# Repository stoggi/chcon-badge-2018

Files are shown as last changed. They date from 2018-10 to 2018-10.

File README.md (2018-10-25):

# chcon-badge-2018
Hardware and Firmware for the ChCon 2018 badge

Made by [@jsstott](https://twitter.com/jsstott) and [@ryankurte](https://twitter.com/ryankurte)

## Assmebling your badge

See [ASSEMBLY.md](ASSEMBLY.md) for instructions, and ask in the [#badge](https://chcon-nz.slack.com/messages/CDN6BFPEV) channel in the [CHCon-NZ](https://join.slack.com/chcon-nz/shared_invite/MjA1MjM5NjY5ODQzLTE0OTg3MDAxOTEtNDUwZTMwMmEwYQ) Slack workspace for help.

## Programming your badge

You will need:

* A recent verison of the [Arduino IDE](https://www.arduino.cc/en/Main/Software) to compile and program the board
* The [Adafruit_NeoPixel](https://learn.adafruit.com/adafruit-neopixel-uberguide/arduino-library-installation) library to control the LEDs
* The [Digistump](https://digistump.com/wiki/digispark/tutorials/connecting) board library
* The EEPROM library found [here](https://github.com/digistump/DigistumpArduino/files/267174/EEPROM.zip) add under Sketch -> Include Library -> Include Zip
* A micro USB cable

To upload new firmware:

1. Open a sketch from the firmware directory.
2. From the Tools menu select Board -> Digispark (Default - 16.5Mhz)
3. From the Tools menu select Programmer -> Micronucleus.
4. Click "Upload" in the IDE. Plug in the badge, and wait 5 seconds.

> Note: Make sure your badge is powered OFF before you plug it into your computer! You can remove the battery for extra safety.

## Badge Challenge

See [CHALLENGE.md](CHALLENGE.md) to get started...

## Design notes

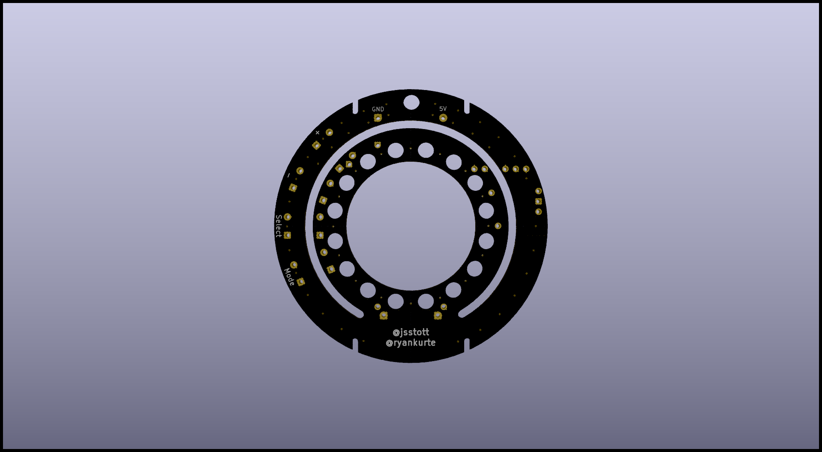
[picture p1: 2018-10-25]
images/back.png

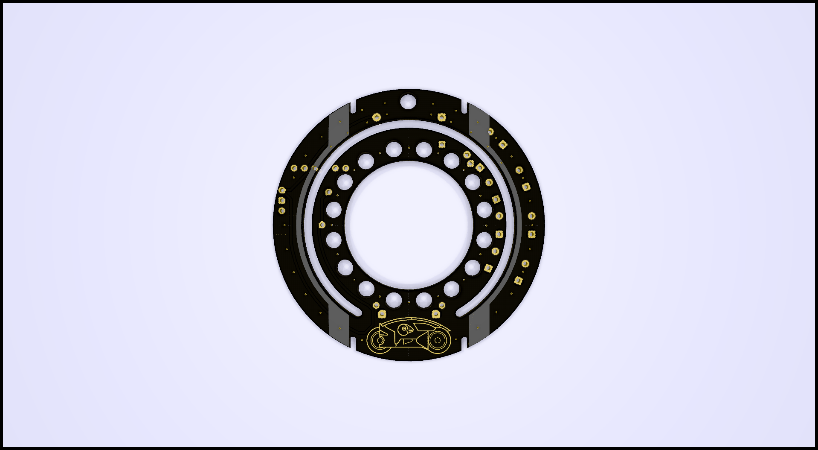
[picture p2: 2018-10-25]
images/front.png

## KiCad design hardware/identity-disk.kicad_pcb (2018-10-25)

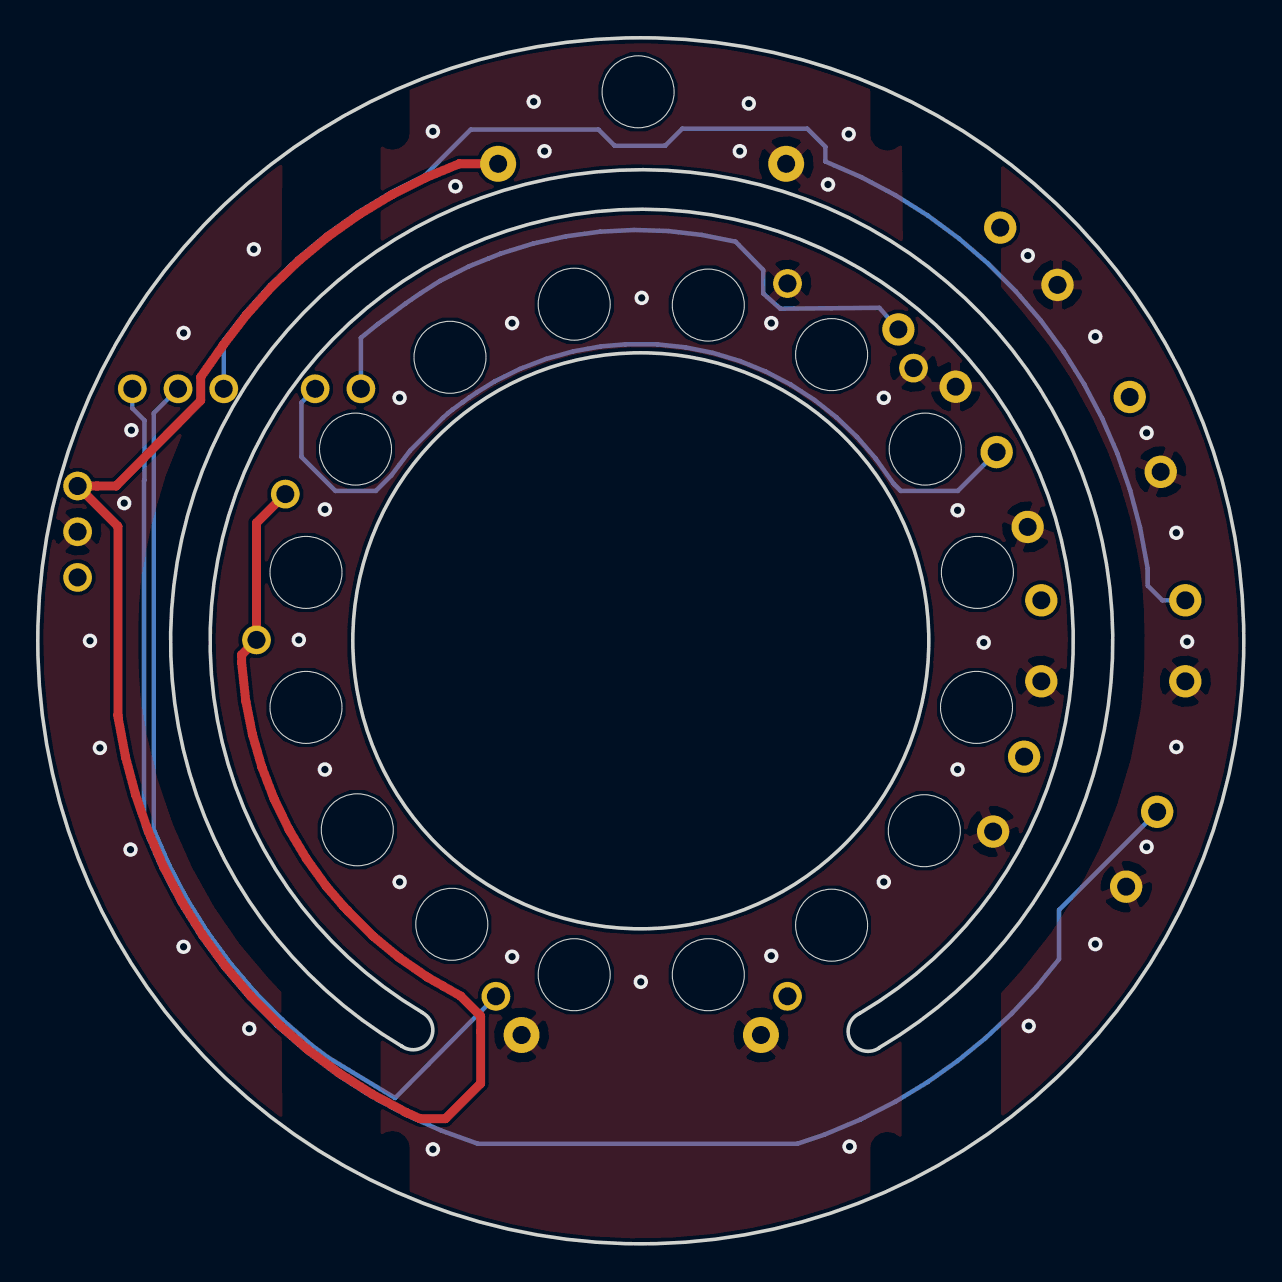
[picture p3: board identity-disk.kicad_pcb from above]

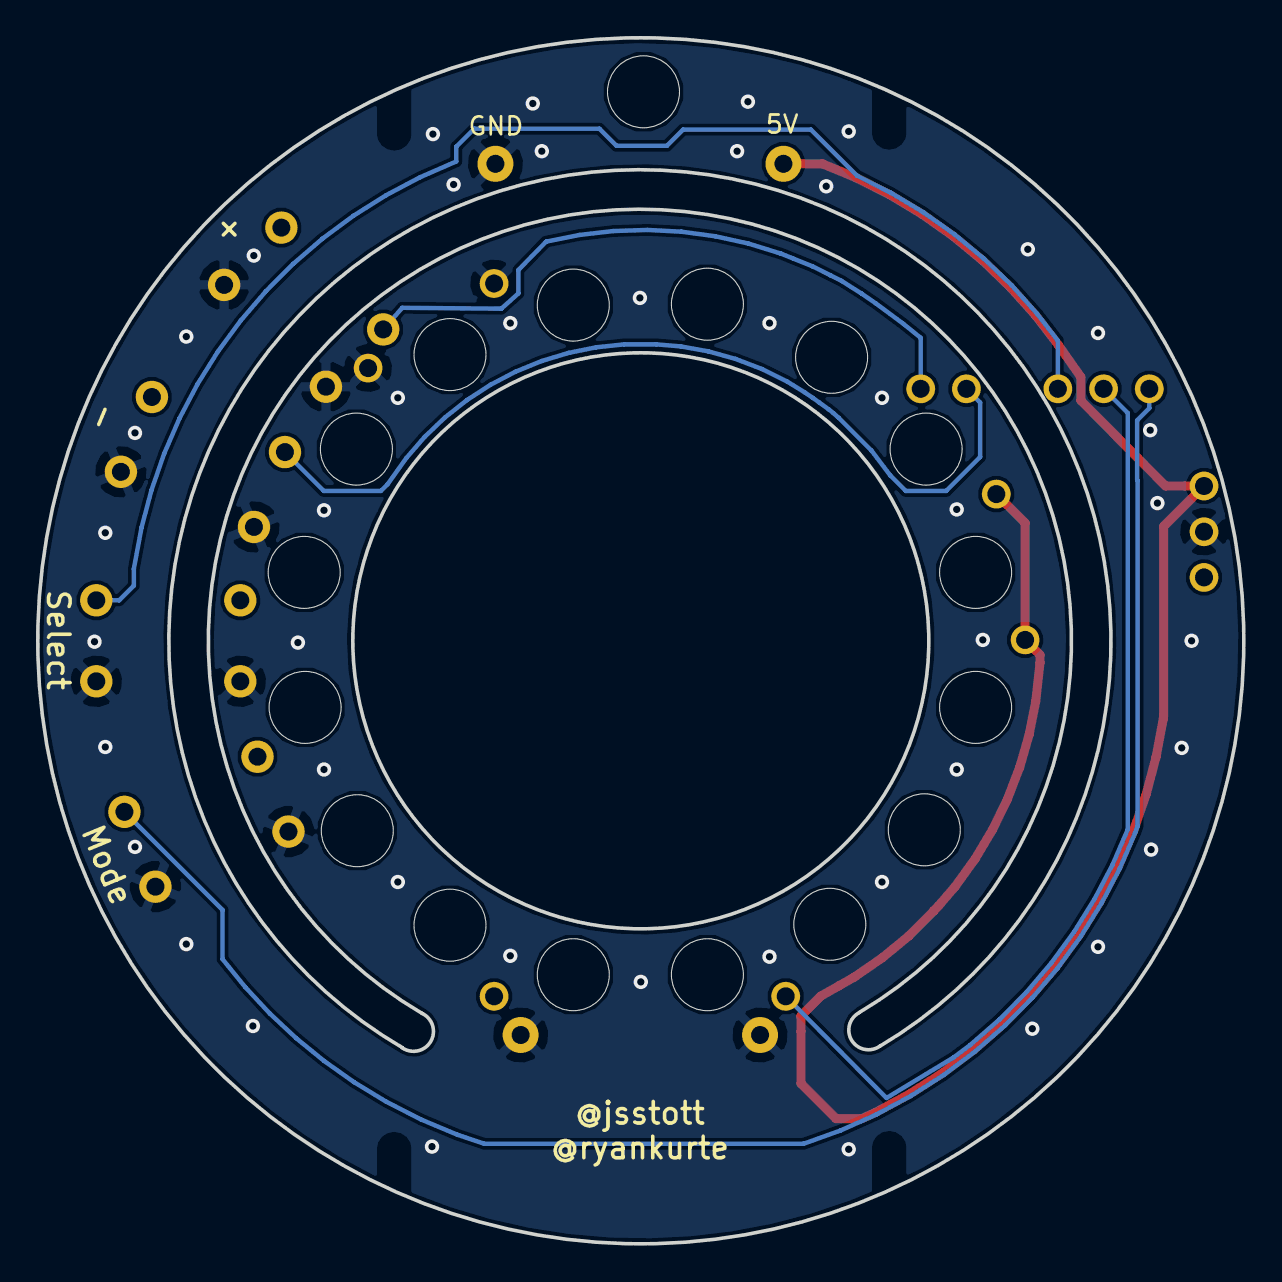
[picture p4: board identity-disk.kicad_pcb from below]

Board: 2 copper layers, 67.0 x 67.0 mm, 14 parts (6 on the bottom side), 7 nets.

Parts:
B1: lilypad
MH1: Lanyard Mount; lanyard_mount
MH2, MH3, MH4, MH5: Edge Cut; route_bite
MH6: Logo; logo
MH7: Front Decal; front-decal
SW1: Mode; switch
SW2: Select; switch
SW3: CCW; switch
SW4: CW; switch
U1: digispark; attiny
U2: ledring

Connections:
/5V: B1.3, U1.3, U2.1
/LED_DATA: U1.5, U2.3
/SW_Minus: SW4.1, U1.9
/SW_Mode: SW1.1, U1.4
/SW_Plus: SW3.1, U1.8
/SW_Select: SW2.1, U1.6
GND: B1.1, B1.2, B1.4, SW1.2, SW2.2, SW3.2, SW4.2, U1.2, U2.2

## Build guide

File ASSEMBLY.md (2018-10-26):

# How to assemble your badge

You will need:
* Soldering iron
* Side cutters
* Safety glasses
* Ventilation

## Step 1

Make sure you have all the parts. You should have in your bag:

* 1 x battery holder + boost converter
* 1 x attiny85 microcontroller board + headers
* 1 x acrylic disk
* 1 x black round PCB with CHCon logo
* 1 x led ring, with 16 RGB leds
* 1 x additional headers

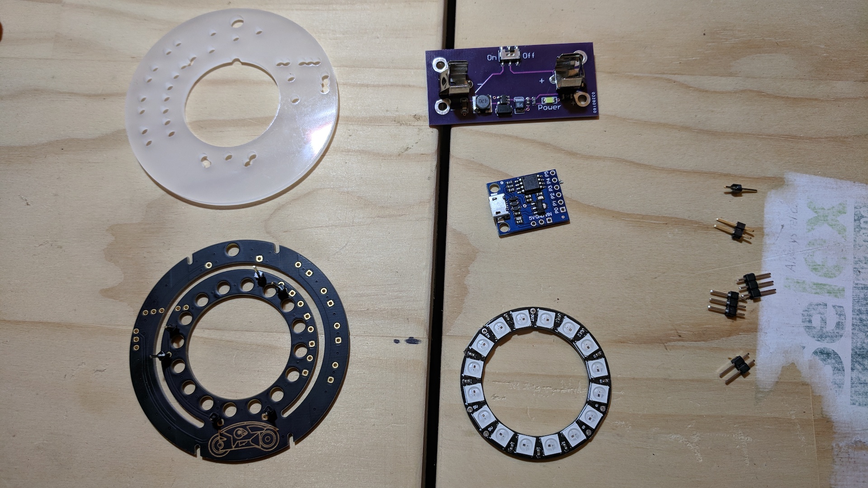
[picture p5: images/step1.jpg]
parts-list


## Step 2

Cut the headers into smaller strips with the side cutters so you have:

```
10 x 1-pin
2 x 3-pin
1 x 2-pin
```

> Note: rest your finger on the end you are cutting off so it doesn't fly away. Wear safety glasses.

Get the 2-pin header, and push it through the back of the PCB, and solder it onto the front (side with the logo).

This step will save us from headaches later. Don't over-do it with solder on these pins, as we won't have much space later on.

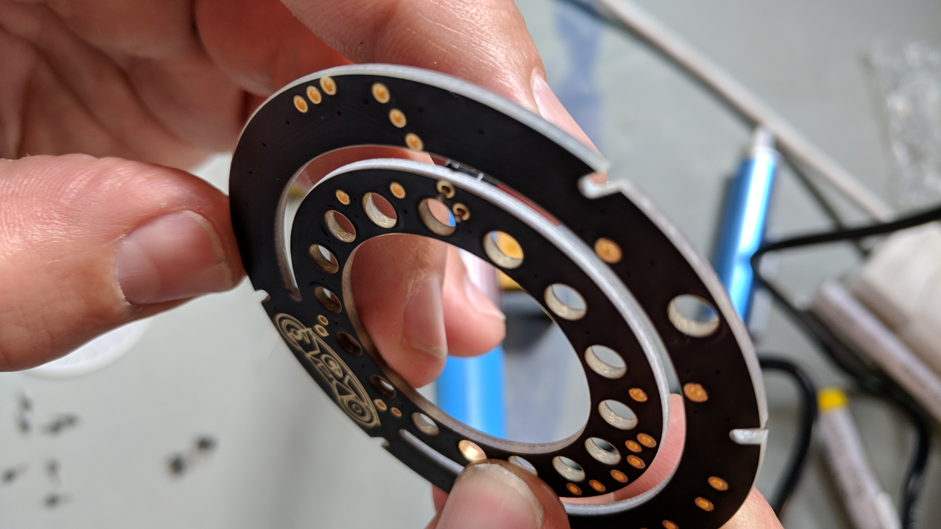
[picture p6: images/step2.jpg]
two-pin-header


## Step 3

On six of the single pin headers, cut off the shorter end with the side cutters.

> Note: same as above, rest your finger on the end you are cutting off so it doesn't fly away. Wear safety glasses.

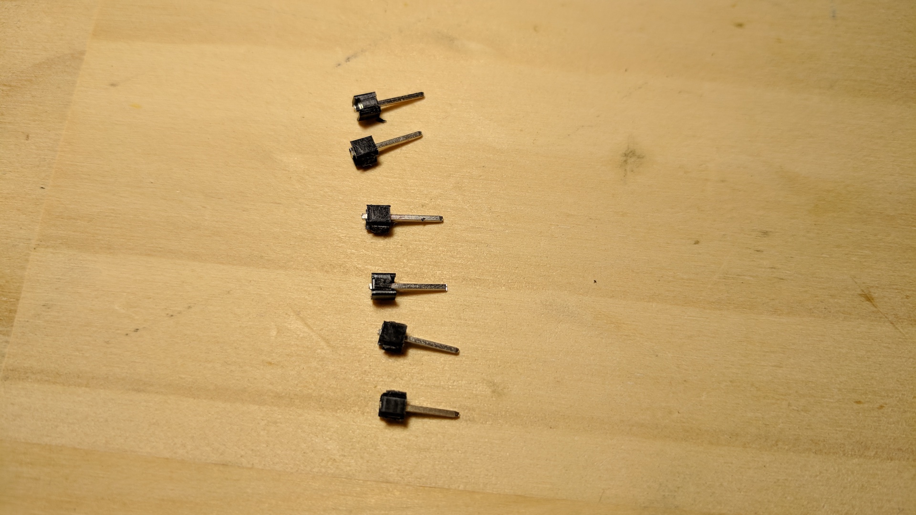
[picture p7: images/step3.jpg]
shorten-headers


## Step 4

Peel the backing off the acrylic disk.
Place the six pins in the disk as shown. You could use tape to keep them in place, on the flush side.

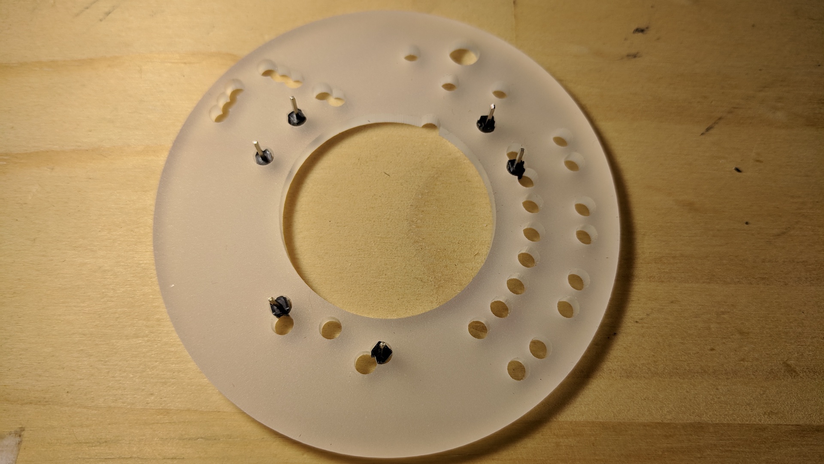
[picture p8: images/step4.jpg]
acrylic-disk


## Step 5

Lay the PCB on top of the 6 pins.

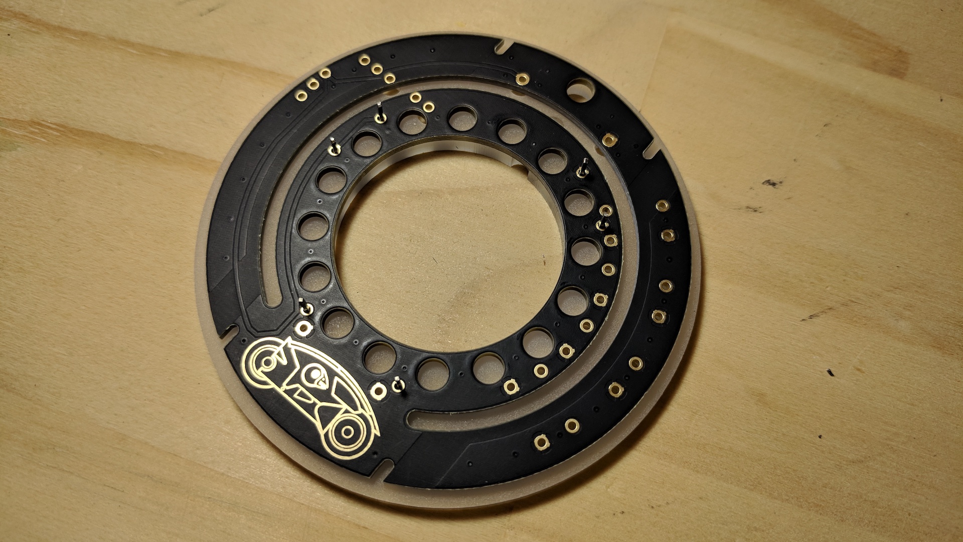
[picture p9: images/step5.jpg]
assemble-pcb


## Step 6

Place the led ring on top of the 6 pins, so that the pins are only just in the holes.

Solder the pins on the bottom PCB.

Push the ring down on the pins.

Solder the pins on the top of the led ring.

> Wear safety glasses, and have proper ventilation while soldering.

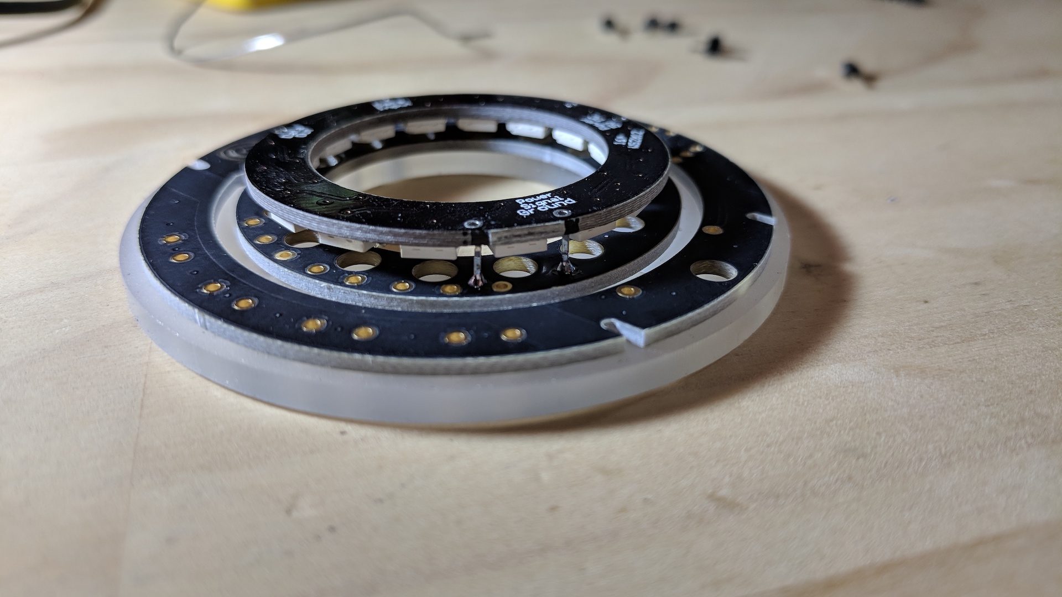
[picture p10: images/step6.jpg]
assemble-ledring


## Step 7

Flip the disk over.

Place the 2-pin, and two 3-pin headers into the disk as shown

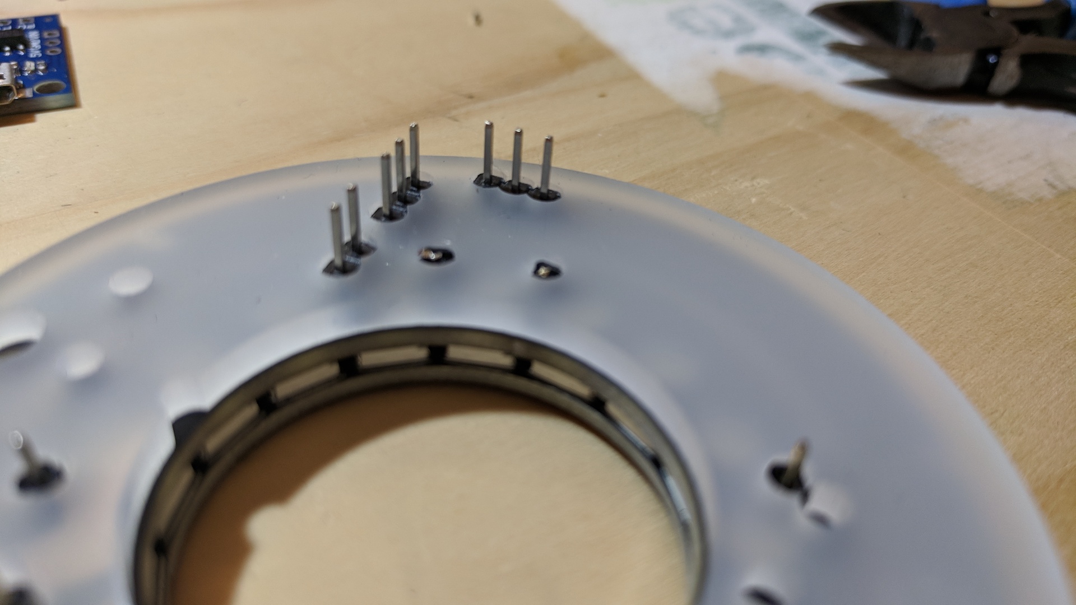
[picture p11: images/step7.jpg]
digispark-headers


## Step 8

Before pushing the attiny85 board down, just make sure the pins that connected the LED ring don't come out past the disk. You could put some tape down to separate the disk and the attiny. If the pin pierces the soldermask on the attiny it might connect 5V to GND.

Push the attiny85 board onto the pins, and solder.

> Wear safety glasses, and have proper ventilation while soldering.

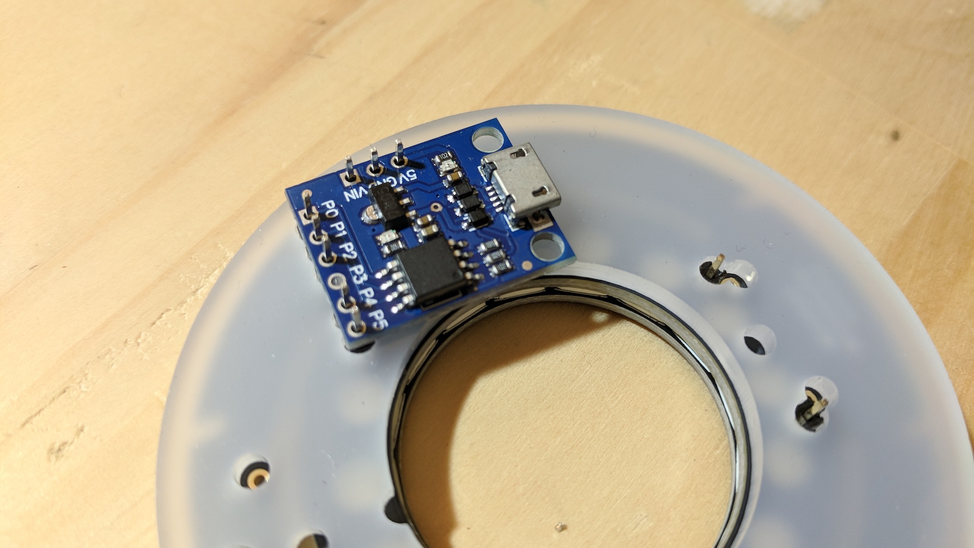
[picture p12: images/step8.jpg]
assemble-digispark


## Step 8a

We need to fix a happy-little-PCB-accident to the board.

Get some wire and connect two pins on the digispark, 5V and VIN. Like so:

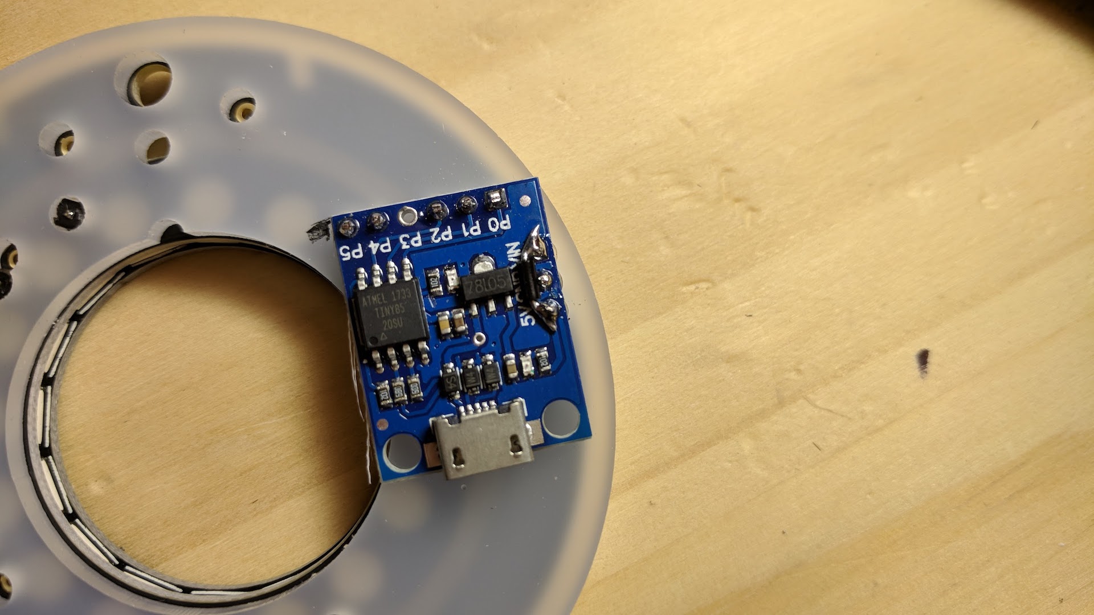
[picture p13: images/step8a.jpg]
pcb-accident


## Step 9

Solder on the other side too.

> Wear safety glasses, and have proper ventilation while soldering.

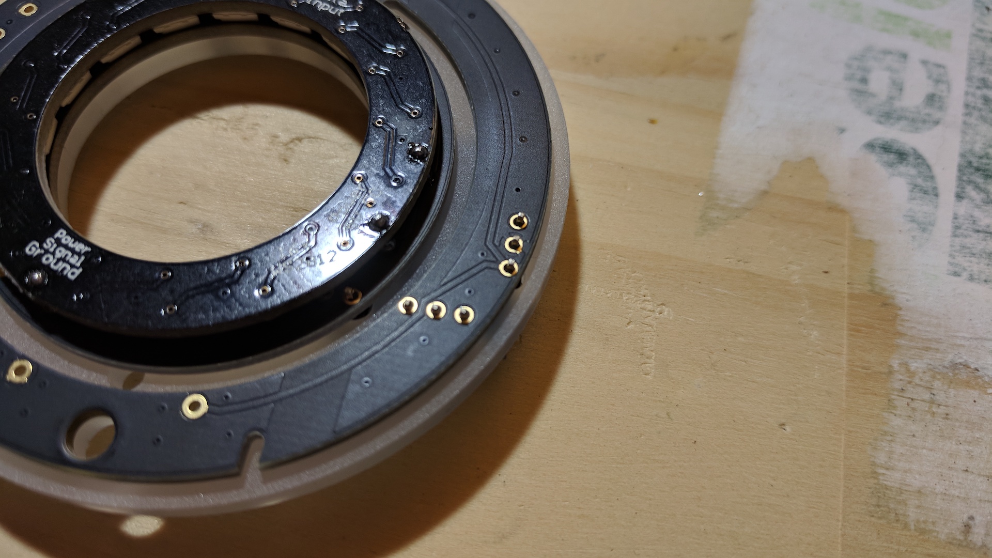
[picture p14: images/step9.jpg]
digispark-other-side


## Step 10

Place the four remaining 1-pin headers like so:

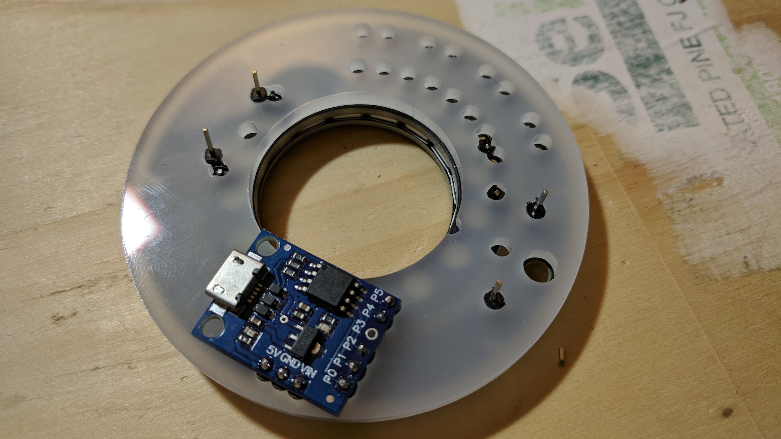
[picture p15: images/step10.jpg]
battery-headers


## Step 11

And solder the battery holder on. Note the orientation must be correct. On/Off switch away from the attiny85 board.

Make sure to solder the other side too.

> Wear safety glasses, and have proper ventilation while soldering.

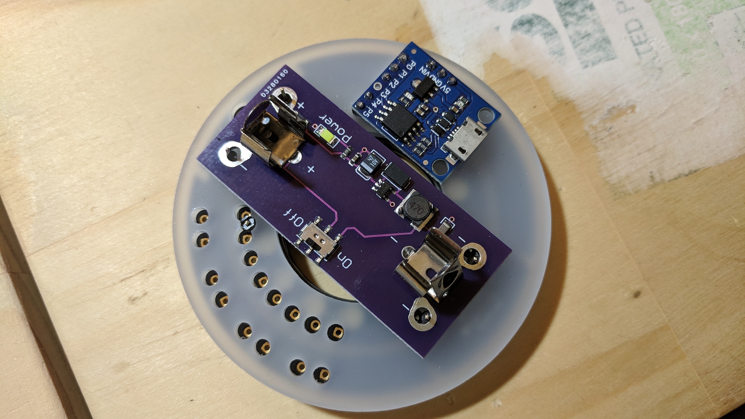
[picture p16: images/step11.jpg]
assemble-battery


## Done

What are the other holes for? Buttons that are somewhere between Shanghai and Auckland :(

You should be able to solder on tactile switches and use them as inputs on the Digispark.

Now you can try the [Badge Challenge](CHALLENGE.md)

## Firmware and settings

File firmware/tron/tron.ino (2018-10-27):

#include <Adafruit_NeoPixel.h>

// Parameter 1 = number of pixels in strip
// Parameter 2 = pin number (most are valid)
// Parameter 3 = pixel type flags, add together as needed:
//   NEO_KHZ800  800 KHz bitstream (most NeoPixel products w/WS2812 LEDs)
//   NEO_KHZ400  400 KHz (classic 'v1' (not v2) FLORA pixels, WS2811 drivers)
//   NEO_GRB     Pixels are wired for GRB bitstream (most NeoPixel products)
//   NEO_RGB     Pixels are wired for RGB bitstream (v1 FLORA pixels, not v2)
Adafruit_NeoPixel strip = Adafruit_NeoPixel(16, 1, NEO_GRB + NEO_KHZ800);


uint32_t Violet = strip.Color(148, 0, 211);
uint32_t Indigo = strip.Color(75, 0, 130);
uint32_t Blue = strip.Color(0, 0, 255);
uint32_t Green = strip.Color(0, 255, 0);
uint32_t Yellow = strip.Color(255, 255, 0);
uint32_t Orange = strip.Color(255, 127, 0);
uint32_t Red = strip.Color(255, 0 , 0);
uint32_t Black = strip.Color(0,0,0);

uint32_t Colors[7] = {
  Red,
  Orange,
  Yellow,
  Green,
  Blue,
  Indigo,
  Violet
};

void setup() {
  strip.begin();
  // Set the brightness between 0 (off) to 255 (full)
  strip.setBrightness(80);
  // Initialize all pixels to off
  strip.show();
}

int W = 0;
int H = 254;
int L = 150;
int G = H;
int B = L;
int GD = -1;
int BD = 1;
float C = 0;
float PHA=3.14;


void loop() {
  for (int i=0; i <16; i++){
    strip.setPixelColor(i, Black);
  }

  G=L+abs(sin(C) * H - L);
  B=L+abs(sin(C+PHA) * H-L);

  uint32_t c = strip.Color(0, G, B);
  C+=3.14/180;
  PHA+=3.14/720;

  strip.setPixelColor(W, c);
  strip.setPixelColor((W+8)%16, c);
  W+=1;
  W%=16;
  strip.show();
  delay(35 + (sin(C)*10));
}

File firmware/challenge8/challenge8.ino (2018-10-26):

#include "stdlib.h"
#include "DigiKeyboard.h"
#include <EEPROM.h>

uint8_t data[16];
uint8_t crc;

void setup() {

  // Read the solutions to challenges 1-7
  for (int i = 0; i < 14; i++) {
    data[i] = EEPROM.read(i);
  }

  data[14] = 0x00; // ?
  data[15] = 0x00; // ?

  // You will also need to know this:
  // data[14] + data[15] = 225

  // Perform a crc-8 on the data
  crc = CRC8(data, 16);

  pinMode(1, OUTPUT);
}

void loop() {

  // If the bytes above are correct, the crc-8 should equal 0xcf
  if (crc == 0xcf) {
    digitalWrite(1, HIGH);
    delay(500);
    digitalWrite(1, LOW);
    delay(500);
  } else {
    digitalWrite(1, HIGH);
  }
}


//CRC-8 - based on the CRC8 formulas by Dallas/Maxim
//code released under the therms of the GNU GPL 3.0 license
byte CRC8(const byte *data, byte len) {
  byte crc = 0x00;
  while (len--) {
    byte extract = *data++;
    for (byte tempI = 8; tempI; tempI--) {
      byte sum = (crc ^ extract) & 0x01;
      crc >>= 1;
      if (sum) {
        crc ^= 0x8C;
      }
      extract >>= 1;
    }
  }
  return crc;
}

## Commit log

2018-10-25 Squashed ;)
    [identity-disk.kicad_pcb, identity-disk.sch]
2018-10-26 Update ASSEMBLY.md
    Updated assembly docs
